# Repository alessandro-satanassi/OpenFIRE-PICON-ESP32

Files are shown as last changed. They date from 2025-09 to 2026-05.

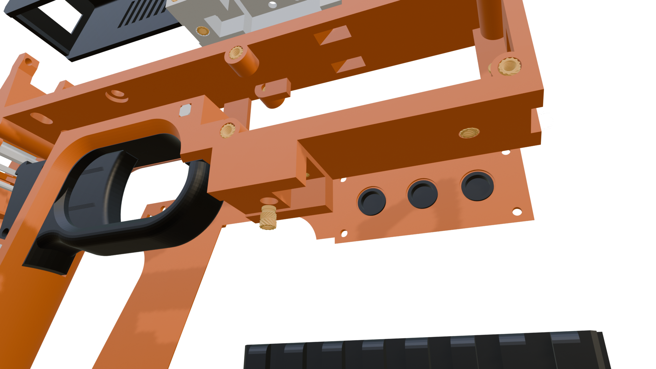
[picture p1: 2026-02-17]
web/files/010---telaio_sotto_pompa_posteriore.png

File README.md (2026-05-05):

# OpenFIRE-PICON-AS-ESP32
Lightgun PICON-AS for OpenFIRE-ESP32
https://alessandro-satanassi.github.io/OpenFIRE-PICON-AS-ESP32/

PICON-AS (nome del progetto: OpenFIRE-PICON-AS-ESP32) è una lightgun derivata dal modello PICON-OG di ICON che nasce per essere utilizzata in modalità completamente WIRELESS; la sua caratteristica distintiva è infatti la capacità di funzionare interamente a batteria, senza la necessità di alcun cavo di collegamento, garantendo una libertà di movimento assoluta anche durante l’uso del rinculo mediante solenoide. Rispetto al progetto originale, da cui riprende la struttura e l'hardware, la maggior parte dei componenti (inclusi molti file .STL) è identica, ma la periferica è stata adattata per semplificare i collegamenti elettrici e supportare appieno la gestione wireless. Per utilizzare tale connessione senza fili, è necessario collegare un dongle wireless a una porta USB del PC (vedi sezione Hardware).

Il cuore del sistema è una cella Li-ion 21700 ricaricabile e non rimovibile, gestita da un hardware di ricarica integrato direttamente nel dispositivo. Per la massima versatilità, la periferica dispone di un ingresso USB-C utile sia per rigenerare la carica sia per l'utilizzo cablato su PC, oltre a un jack per alimentazione esterna a 12V; quest'ultimo permette di azionare solenoide e circuiti preservando la batteria e ricaricandola simultaneamente. La dotazione comprende un interruttore di accensione generale, uno switch dedicato per disattivare il rinculo e un indicatore LED per il monitoraggio del livello di carica.

PICON-AS supporta numerose funzionalità, tra cui rumble, rinculo con solenoide, display OLED, LED Neopixel, joystick analogico, D-PAD, pulsanti START, SELECT, A,B,C e switch a pompa. N.B. Sebbene il sistema sia compatibile con tutte queste feature, l'installazione della maggior parte di esse rimane opzionale e a discrezione dell'utente.

A livello software, la lightgun è compatibile con il firmware originale per RP2040, ma le funzionalità aggiuntive sono disponibili solo utilizzando un microcontrollore ESP32-S3 con il firmware OpenFIRE-firmware-ESP32 (vedi sezione Hardware). Questo firmware per ESP32 è un porting del firmware originale (con cui mantiene piena compatibilità), al quale sono state apportate solo poche modifiche e l’aggiunta del supporto wireless. Si ringraziano gli autori dei progetti originali PICON-OG e OpenFIRE per il lavoro su cui si basa questo progetto.

===============================================================
Lightgun PICON-AS for OpenFIRE-ESP32
https://alessandro-satanassi.github.io/OpenFIRE-PICON-AS-ESP32/

PICON-AS (project name: OpenFIRE-PICON-AS-ESP32) is a lightgun derived from ICON's PICON-OG model, designed to be used in a completely WIRELESS mode; its distinctive feature is indeed the ability to operate entirely on battery power, without the need for any connecting cables, ensuring absolute freedom of movement even when using the solenoid recoil. Compared to the original project, from which it inherits the structure and hardware, most of the components (including many .STL files) are identical, but the peripheral has been adapted to simplify the electrical connections and fully support wireless management. To use this wireless connection, a wireless dongle must be connected to a USB port on the PC (see the Hardware section).

The heart of the system is a rechargeable and non-removable 21700 Li-ion cell, managed by charging hardware integrated directly into the device. For maximum versatility, the peripheral features a USB-C input, which is useful both for recharging and for wired use on a PC, as well as a 12V external power jack. The latter allows the solenoid and circuits to be operated while preserving the battery and charging it simultaneously. The equipment includes a main power switch, a dedicated switch to disable the recoil, and a LED indicator to monitor the charge level.

PICON-AS supports numerous features, including rumble, solenoid recoil, OLED display, Neopixel LEDs, analog joystick, D-PAD, START, SELECT, A, B, C buttons, and a pump-action switch. N.B. Although the system is compatible with all these features, the installation of most of them remains optional and at the user's discretion.

On the software side, the lightgun is compatible with the original firmware for RP2040, but the additional features are only available by using an ESP32-S3 microcontroller with the OpenFIRE-firmware-ESP32 firmware (see the Hardware section). This ESP32 firmware is a port of the original firmware (with which it maintains full compatibility), to which only a few modifications and the addition of wireless support have been made. Special thanks go to the authors of the original PICON-OG and OpenFIRE projects for the work on which this project is based.

============================================

OpenFIRE-PICON-ESP32 è un progetto derivato da Picon-OG, creato da iCON.  
Questa opera è distribuita sotto licenza Creative Commons Attribution-NonCommercial-ShareAlike 4.0 International (CC BY-NC-SA 4.0), come il progetto da cui è derivato.

================== licenza ===================================
https://creativecommons.org/share-your-work/cclicenses/
CC BY-NC-SA
This license enables reusers to distribute, remix, adapt, and build upon the material in any medium or format for noncommercial purposes only, and only so long as attribution is given to the creator. If you remix, adapt, or build upon the material, you must license the modified material under identical terms. CC BY-NC-SA includes the following elements:

 BY: credit must be given to the creator.
 NC: Only noncommercial uses of the work are permitted.
 SA: Adaptations must be shared under the same terms.
==============================================================

Il progetto Picon-OG
================================================================================================
https://diylightgun.com/lightgun-details/?lgid=506
============================================================
PiCON-OG
3D Printed Lightgun by iCON

Smaller, lighter version of the iCON featuring a sliding recoil, rumble motor, pump reload, analog joystick, 5-way navigation, OLED display, NeoPixel LED in back, accelerometer, screw in wide angle or fish eye lens connection. All parts (including the one-piece frame) can be printed on an Ender 3. The OLED, NeoPixel LED, accelerometer and analog joystick will only work with OpenFIRE firmware running on a Raspberry Pi RP2040 based microcontroller (Pico, Pico W, RP2040 Zero).

The author marked this model as their own original creation.
This work is licensed under a CC BY-NC-SA Creative Commons (4.0 International License)
================================================================================================

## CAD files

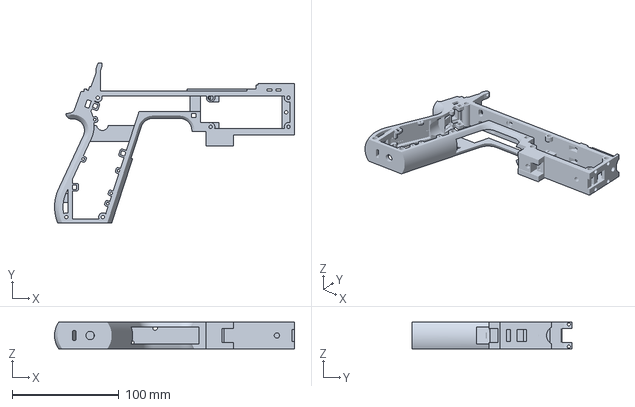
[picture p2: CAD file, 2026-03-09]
FreeCAD/definitivo/PICON-OF_ver_65-Cut055.3mf
224.6 x 149.8 x 25.2 mm

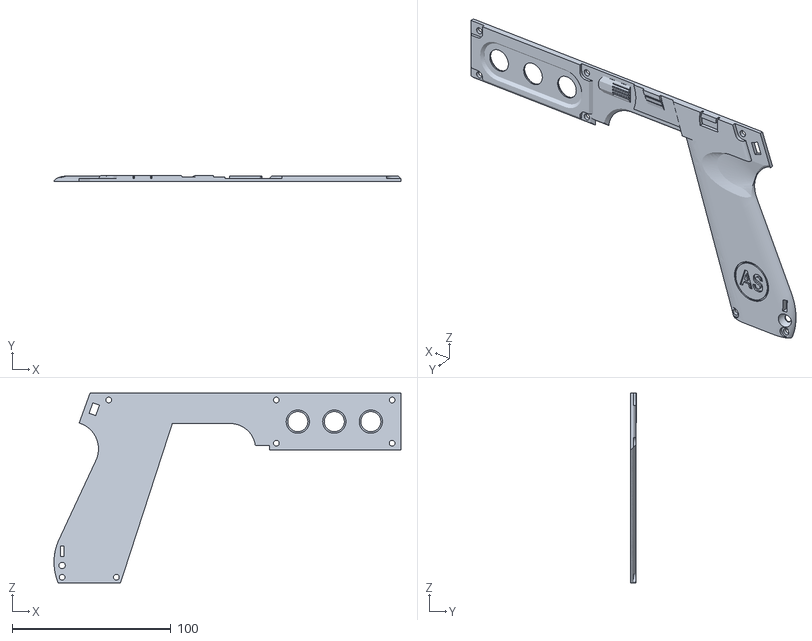
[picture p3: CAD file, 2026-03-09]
FreeCAD/lati/PICON-OF_ver_52-lato SX.stl
218.6 x 4.00 x 119.6

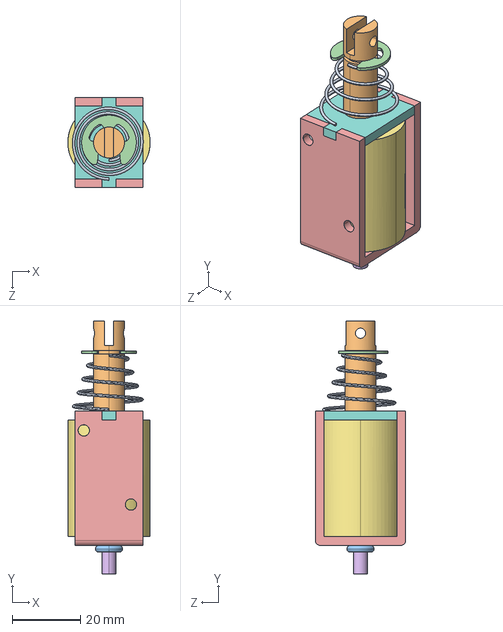
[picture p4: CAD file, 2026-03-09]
FreeCAD/Parts/JF-1039.STEP
24.2 x 74.4 x 26.6 mm

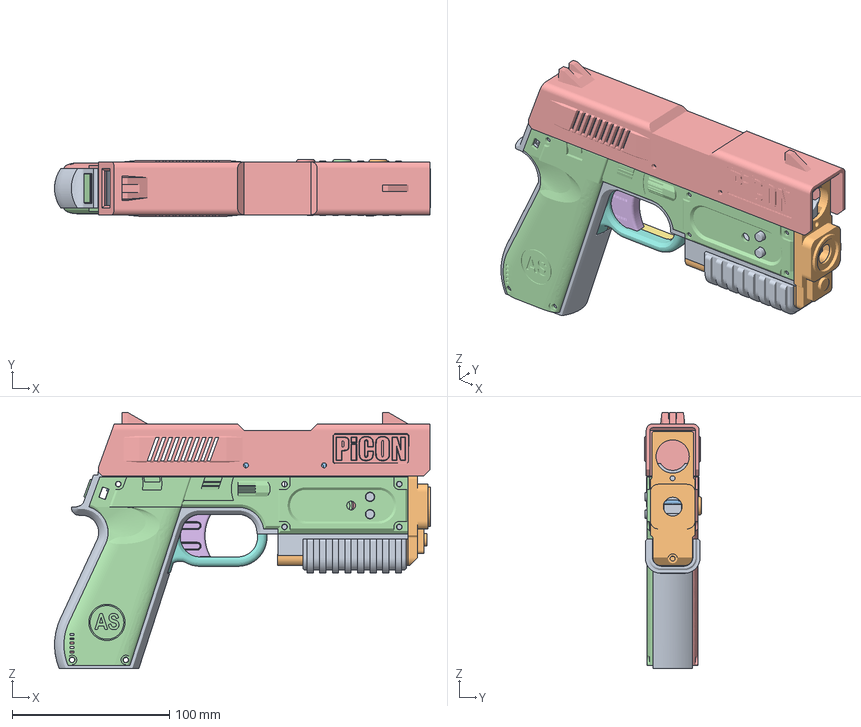
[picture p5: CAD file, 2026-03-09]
FreeCAD/PICON-AS-EXPLODED.FCStd
238.8 x 36.0 x 162.8 mm
PICON-OF_ver_64-Cut055
frontale_analogico_corretto-Cut
PICON-OF_ver_37-blocco switch
PICON-OF_ver_53-lato DX
PICON-OF_ver_52-lato SX
PICON-OF_ver_37-perno fermo grilletto -front
PICON-OF_ver_37-perno fermo rumble
PICON-OF_ver_37-perno fermo neopixel
PICON-OF_ver_37-pulsanti lato destro
PICON-OF_ver_37-pulsanti lato sinistro_A
PICON-OF_ver_61-Protezione_inferiore_batteria
PICON-OF_ver_37-supporto per neopixel
slide-oled
trigger
trigger-guard-left
trigger-guard-right
pump
pump-mount-1
bearing-solenoid-mount
PICON-OF_ver_37-pulsanti lato sinistro_B
PICON-OF_ver_37-pulsanti lato sinistro_C
PICON-OF_ver_37-perno fermo bq25185
PICON-OF_ver_37-perno fermo grilletto -rear
PICON-OF_ver_37-perno fermo switch
PICON-OF_ver_37-perno fermo step-down
PICON-OF_ver_37-perno fermo power-path
PICON-OF_ver_37-perno fermo mp3429
PICON-OF_ver_37-perno fermo driver

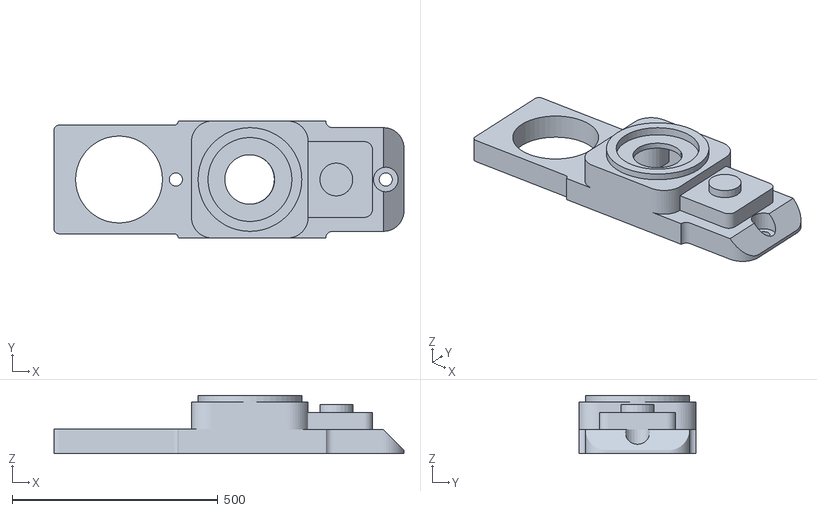
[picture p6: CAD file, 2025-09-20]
FreeCAD/STL_PICON_AS/ANTERIORE_con_buco_ANALOG_STICK/frontale_analogico-Cut.stl
850.2 x 284.0 x 142.0

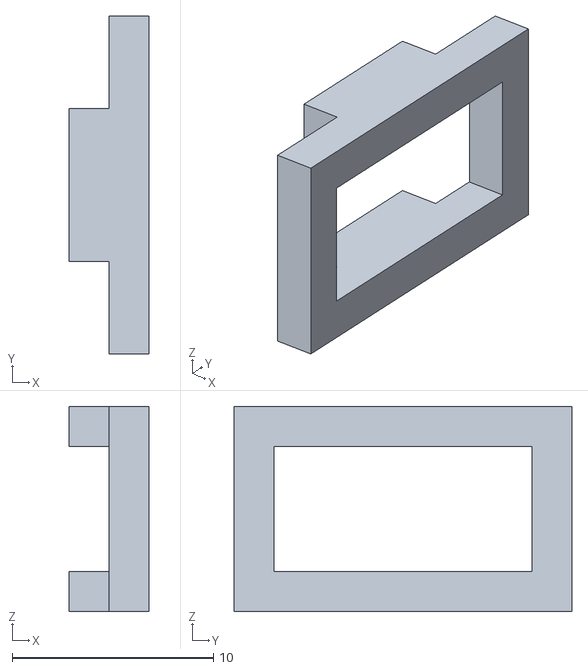
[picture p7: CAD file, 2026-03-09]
FreeCAD/STL_PICON_AS/blocco_SWITCH/PICON-OF_ver_37-blocco switch.stl
4.00 x 16.8 x 10.2

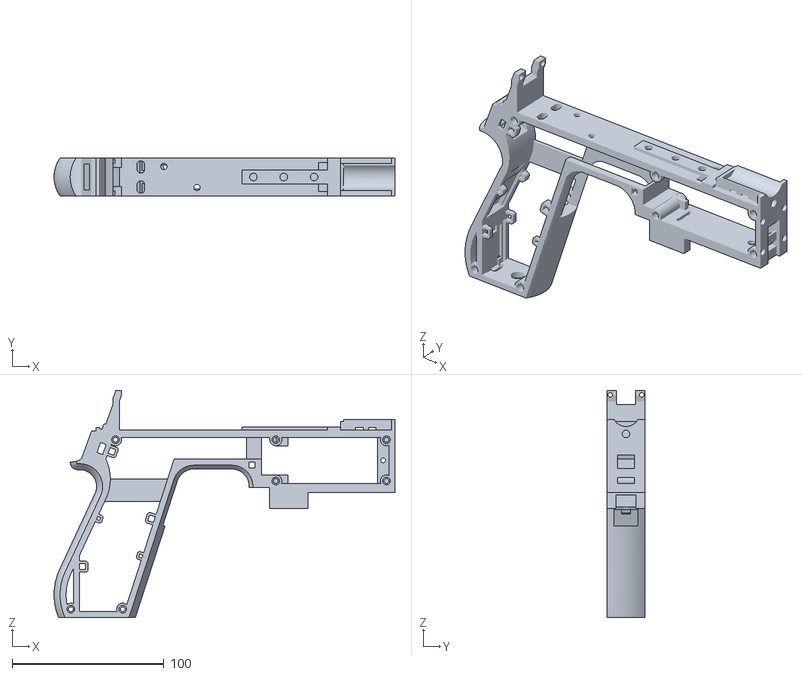
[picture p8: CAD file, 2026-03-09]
FreeCAD/STL_PICON_AS/CORPO_pistola/PICON-OF_ver_37-Cut043.stl
224.6 x 25.2 x 149.8

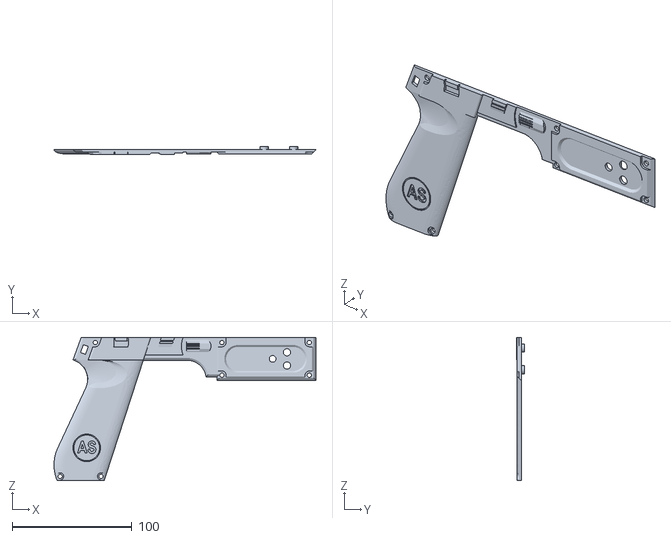
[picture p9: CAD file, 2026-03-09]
FreeCAD/STL_PICON_AS/lato_DX_pistola/PICON-OF_ver_37-lato DX.stl
218.6 x 6.40 x 119.6

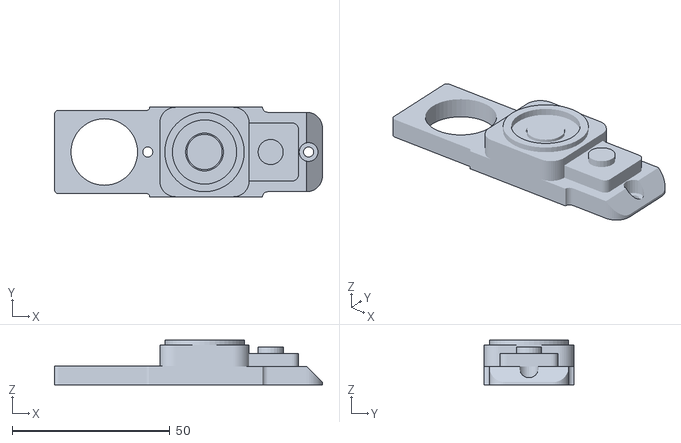
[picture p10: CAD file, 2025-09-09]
FreeCAD/STL_PICON_AS/ORIGINALI_PICON_OG/ANTERIORE/front-1.stl
85.0 x 28.4 x 14.2

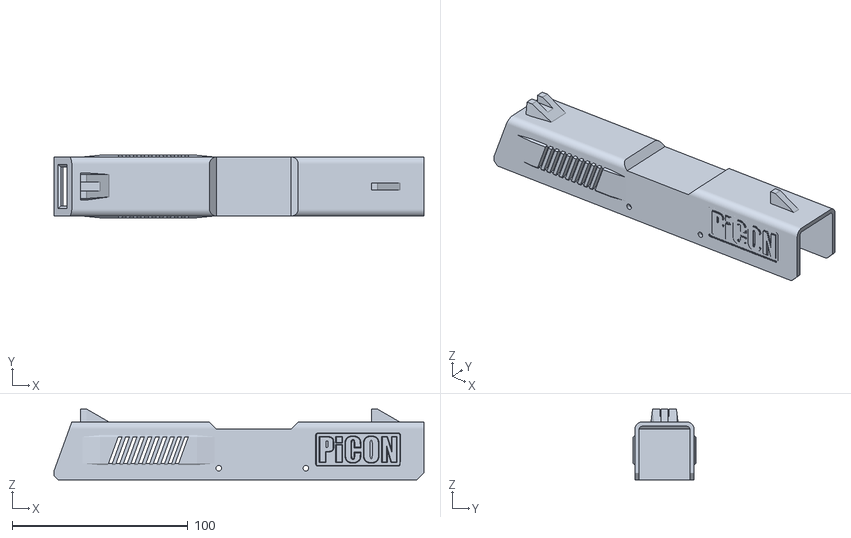
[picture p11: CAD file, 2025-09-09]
FreeCAD/STL_PICON_AS/ORIGINALI_PICON_OG/CASTELLO_PISTOLA/slide-oled.stl
210.6 x 35.6 x 40.4

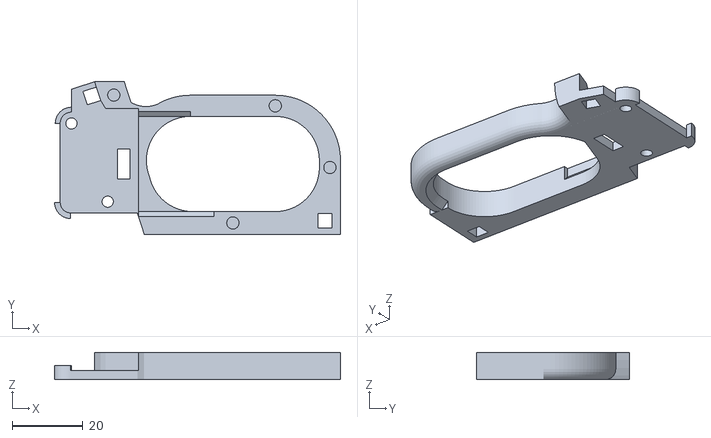
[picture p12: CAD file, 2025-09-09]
FreeCAD/STL_PICON_AS/ORIGINALI_PICON_OG/GRILLETTO/trigger-guard-right.stl
81.1 x 43.3 x 7.80

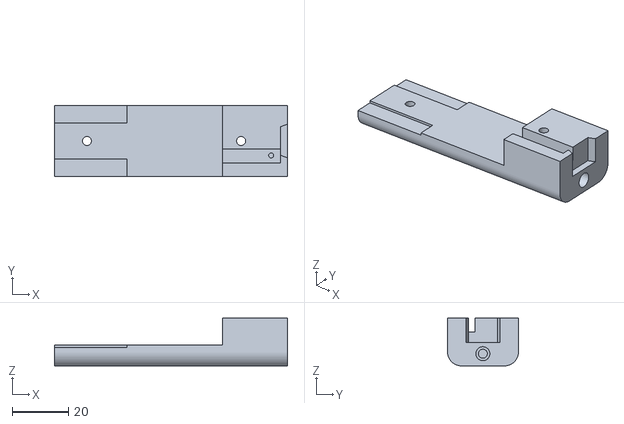
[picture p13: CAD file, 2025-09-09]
FreeCAD/STL_PICON_AS/ORIGINALI_PICON_OG/MECCANISMO_POMPA/pump-mount-1.stl
82.7 x 25.2 x 17.0

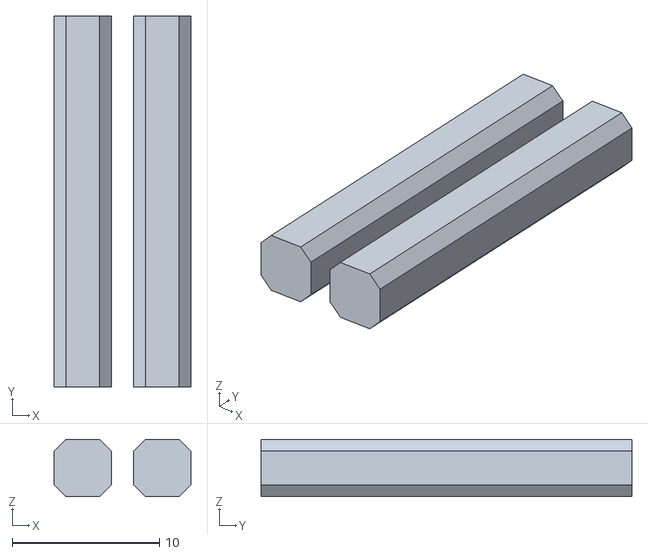
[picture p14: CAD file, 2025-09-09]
FreeCAD/STL_PICON_AS/ORIGINALI_PICON_OG/PERNI_FERMI_GRILLETTO/trigger-guard-pins.stl
9.30 x 25.2 x 3.90

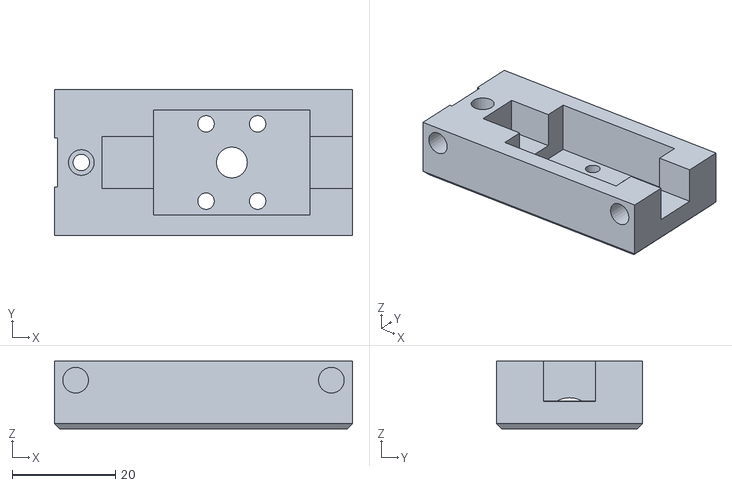
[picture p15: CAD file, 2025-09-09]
FreeCAD/STL_PICON_AS/ORIGINALI_PICON_OG/SUPPORTO_SOLENOIDE_LINEAR_RAIL/bearing-solenoid-mount.stl
57.8 x 28.4 x 13.1

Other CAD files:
FreeCAD/STL_PICON_AS/lato_SX_pistola/PICON-OF_ver_37-lato SX.stl
FreeCAD/STL_PICON_AS/PERNI fermo switch - caricabatterie - grilletto/PICON-OF_ver_37-perno fermo switch - caricabatterie - grilletto.stl
FreeCAD/STL_PICON_AS/PERNI_fermi_rumble_e_driver_solenoide/PICON-OF_ver_37-perno fermo rumble e driver solenoide.stl
FreeCAD/STL_PICON_AS/PERNO_fermo_NEOPIXEL/PICON-OF_ver_37-perno fermo neopixel.stl
FreeCAD/PICON-AS-EXPLODED - INIZIALE - completa_pezzi_posizionati.FCStd
FreeCAD/PICON-AS-EXPLODED - INIZIALE - ver.2 - completa_pezzi_posizionati.FCStd
FreeCAD/PICON-AS-EXPLODED - INIZIALE exploded - ver.10 - completa_pezzi_posizionati.FCStd
FreeCAD/PICON-AS-EXPLODED - INIZIALE exploded - ver.11 - completa_pezzi_posizionati.FCStd
FreeCAD/PICON-AS-EXPLODED - INIZIALE exploded - ver.12 - completa_pezzi_posizionati.FCStd
FreeCAD/PICON-AS-EXPLODED - ver.1 - completa_pezzi_posizionati.FCStd
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

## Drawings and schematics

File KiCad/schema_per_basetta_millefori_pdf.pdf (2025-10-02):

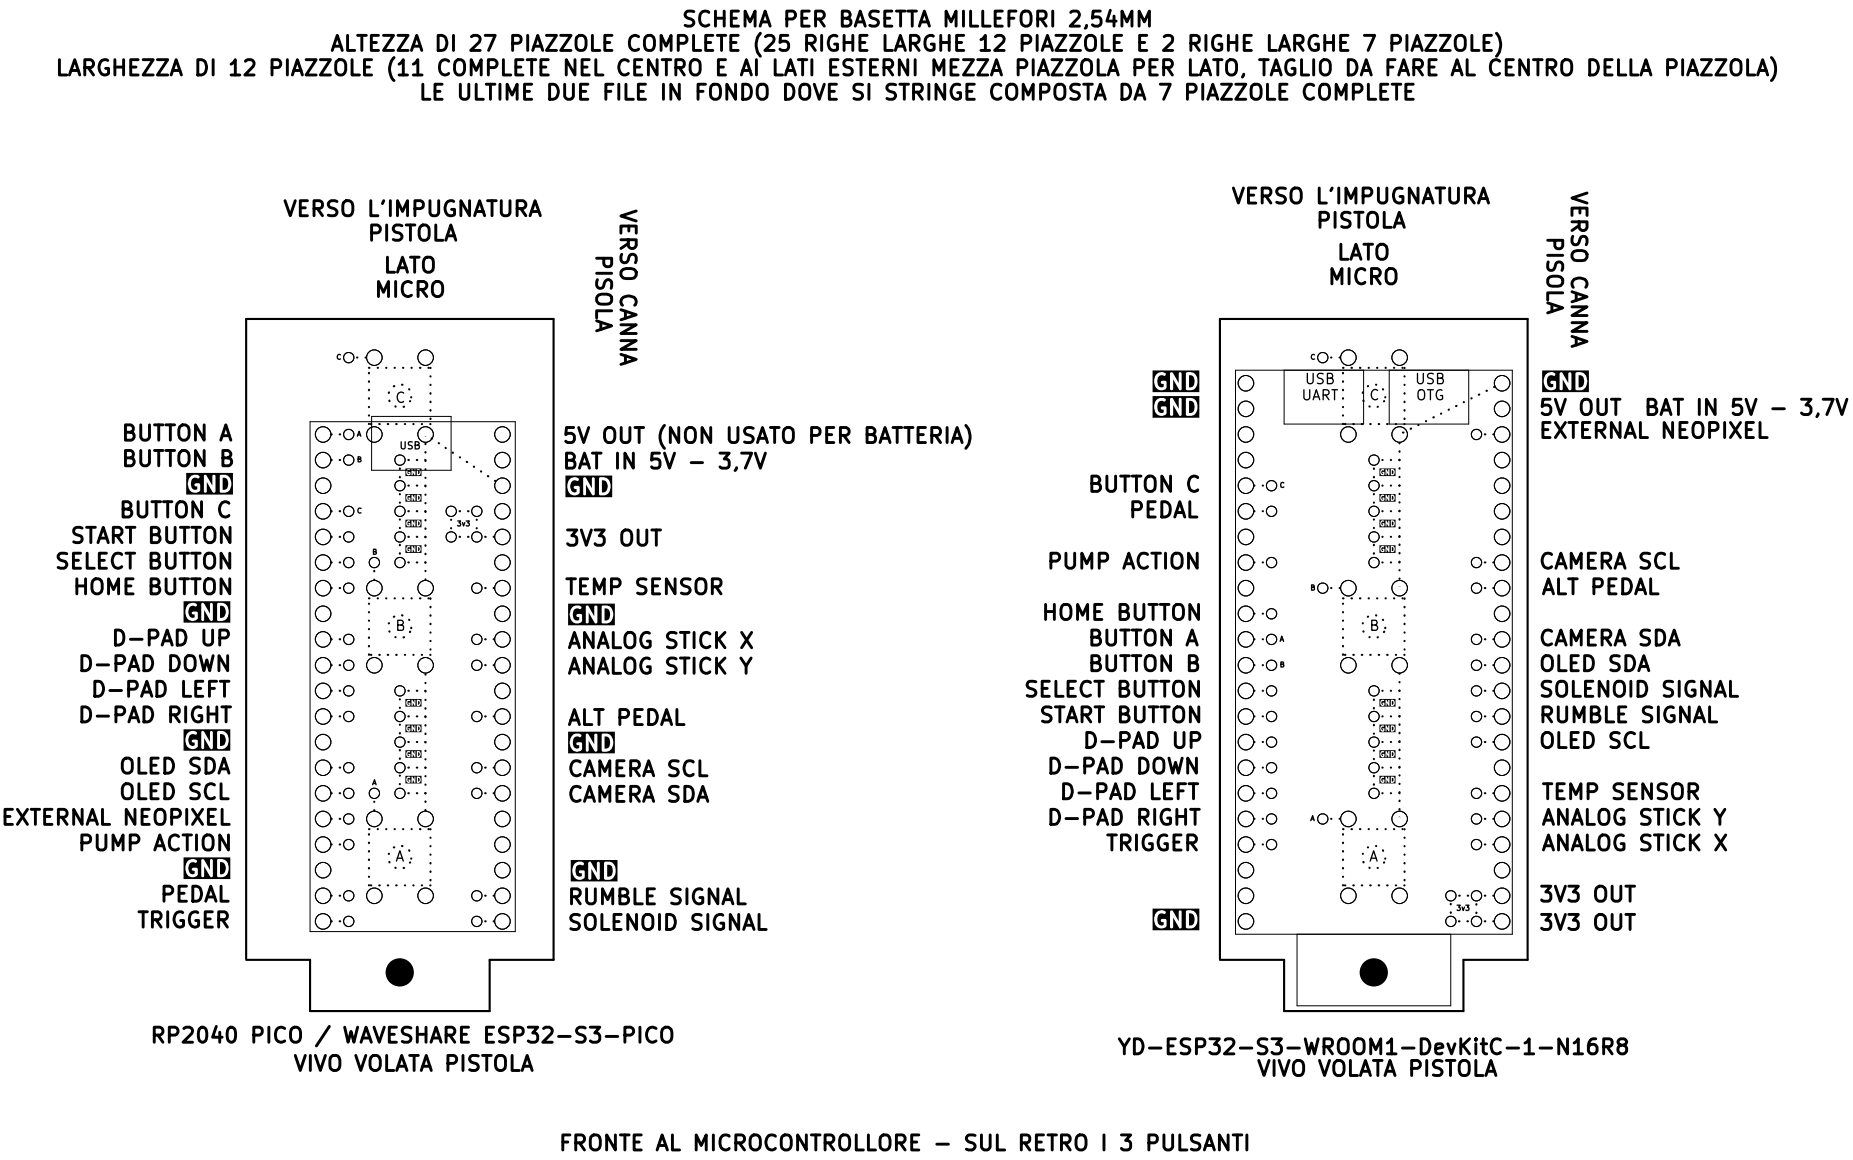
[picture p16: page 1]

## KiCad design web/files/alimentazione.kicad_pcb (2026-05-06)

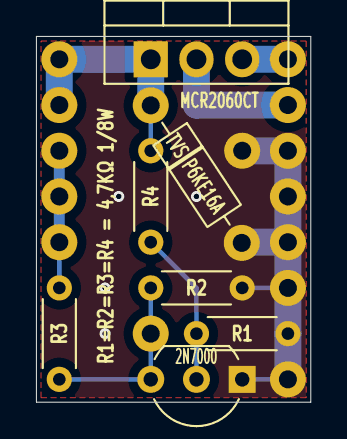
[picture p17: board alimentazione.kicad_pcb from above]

Board: 2 copper layers, 15.2 x 20.3 mm, 7 parts (0 on the bottom side), 4 nets.

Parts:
2N7000: TO-92_Inline_Wide
MCR2060CT: TO-220-3_Vertical
R1: R1; R_Axial_DIN0204_L3.6mm_D1.6mm_P5.08mm_Horizontal
R2: R2; R_Axial_DIN0204_L3.6mm_D1.6mm_P5.08mm_Horizontal
R3: R3; R_Axial_DIN0204_L3.6mm_D1.6mm_P5.08mm_Horizontal
R4: R4; R_Axial_DIN0204_L3.6mm_D1.6mm_P5.08mm_Horizontal
TVS P6KE16A: D_DO-41_SOD81_P9.158mm_Horizontal

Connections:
12V_EXTERN: MCR2060CT.1, R4.2, TVS P6KE16A.1
EN_BOOSTER: 2N7000.3, R2.1, R3.1
GATE_CONTROL_12V: 2N7000.2, R1.1, R4.1
GND: 2N7000.1, R1.2, R2.2, TVS P6KE16A.2

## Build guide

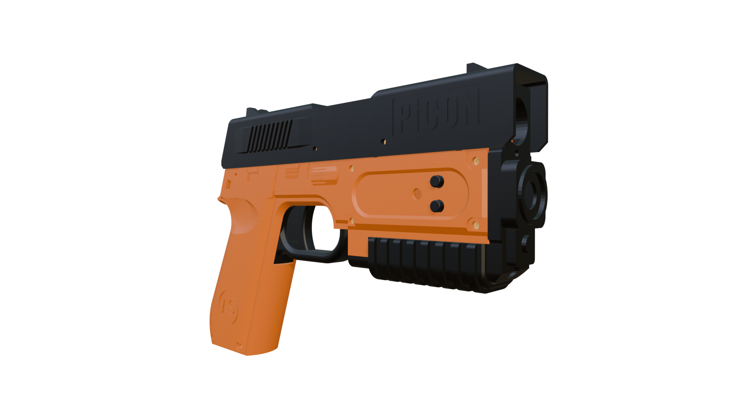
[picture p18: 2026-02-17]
web/files/ASSEMBLATO_stl_FRONT_Sx.png

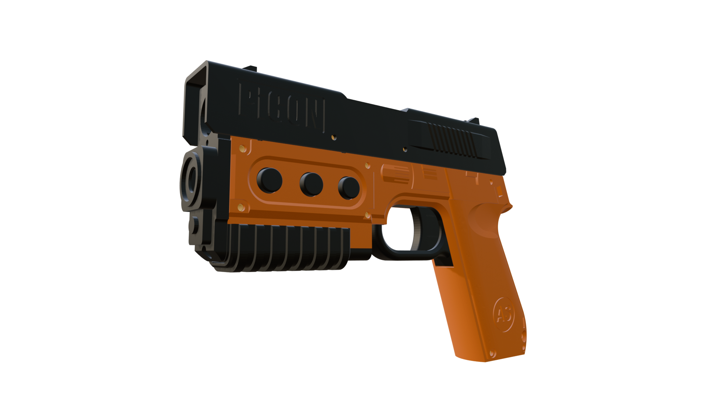
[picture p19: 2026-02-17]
web/files/ASSEMBLATO_stl_FRONT_Dx.png

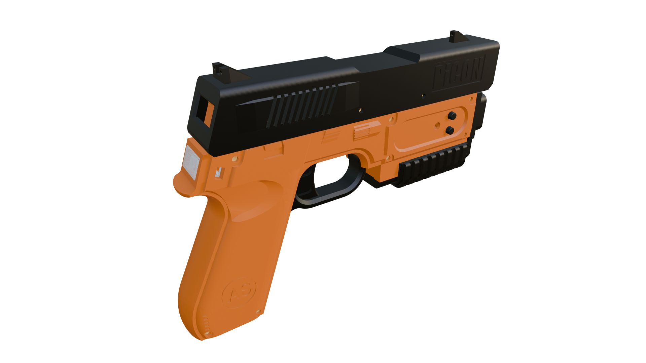
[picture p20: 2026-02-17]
web/files/ASSEMBLATO_stl_dx_bop5vutl.png

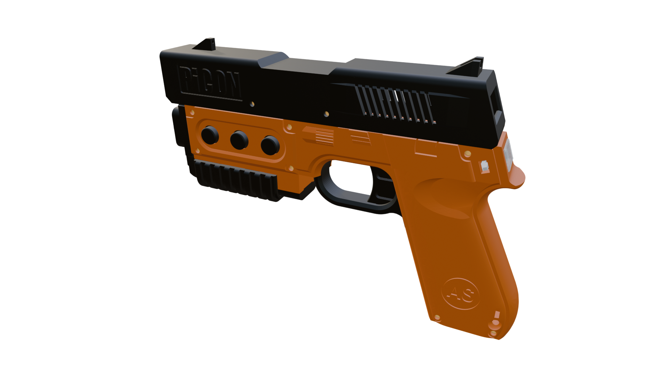
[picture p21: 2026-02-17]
web/files/ASSEMBLATO_stl_Sx.png

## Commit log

2025-09-09 inserimento file originali di picon-og e file di lavoro del progetto dalla versione 12
    inserimento file originali di picon-og e file di lavoro del progetto dalla versione 12
    [PICON-OF_ver_12_completo_con_inclusione_switch-Cut040.stl, back-exposed-rgb-led.stl, back-hidden-rgb-led-2.stl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]
2025-09-11 nuove versioni
    [13_dopo_inclusione.stl, PICON-OF-ver_15.stl]
2025-09-20 aggiornamento e utilità
    [PICON-OF_ver_16-Cut043.stl, PICON-OF_ver_6-Extrude perno fermo rumble _ varie misure.3mf, PICON-OF_ver_6-Extrude perno fermo rumble.stl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]
2025-09-21 aggiunto progetto kicad
    [PICON-AS_SCHEME.kicad_pcb, PICON-AS_SCHEME.kicad_sch]
2025-09-22 NUOVA VERSIONE MILLEFORI
    [PICON-AS_SCHEME.kicad_pcb]
2025-09-30 prima versione di stampa
    [PICON-AS_SCHEME.kicad_pcb, PICON-AS_SCHEME.kicad_sch]
2025-09-30 INSERIMENTO RP2040 - ESP32 PICO
    [PICON-AS_SCHEME_DEFINITIVO.kicad_pcb, PICON-AS_esp32-s3_pico-rp2040_pico.kicad_pcb, PICON-AS_esp32-s3_pico-rp2040_pico.kicad_pcb_bom.csv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]
2025-10-02 INSERIMENTO_IMMAGINI_ E PROGETTI KIKAD
    [PICON-AS_esp32-s3_pico-rp2040_pico.kicad_pcb, PICON-AS_esp32-s3_wroom1-DevKitC-1-N16R8.kicad_pcb, PICON-AS_schema_PCB_millefori.kicad_pcb]
2026-02-21 inserito power-path
2026-02-21 aggiunto driver solenoide
2026-02-22 aggiunte alcune board da completare
2026-02-23 AGG SOLENOIDE E CAM
2026-03-09 aggiornamento file freecad - VERSIONE DEFINITIVA WIRELESS CON SWITCH GROSSI
    [BQ25185.STEP, Camera IR.STEP, ESP32.step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]
2026-03-11 inserimento istruzioni switch
2026-03-12 agg. jack 12v
2026-03-12 agg. stl
    [PICON-OF_ver_65-Cut055.stl]
2026-05-05 AGGIORNAMENTO SITO .. INIZIO INTRODUZIONE PEDALE, INSERIMENTO FILE GERBER, VARIE
    [Base.STL, Lid.STL, Pedal-Frame.STL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]
2026-05-06 agg inserimento file kicad
    [PICON-AS_esp32-s3_pico-rp2040_pico_PAD_gpio.kicad_pcb, PICON-AS_esp32-s3_wroom1-DevKitC-1-N16R8-_-PAD_gpio.kicad_pcb, alimentazione.kicad_pcb]
2026-06-12 aggiunti file freecad
    [PICON-OF_ver_68.FCStd, case_ir_led_tx_ver_04.FCStd, frontale_analogico_corretto.FCStd]
